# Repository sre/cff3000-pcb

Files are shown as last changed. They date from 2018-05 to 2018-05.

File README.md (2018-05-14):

CFF3000 GPIO interface
======================

This repository contains information how to interface a Abus CFF3000
remote control with a Raspberry Pi or similar development board using
GPIOs. First of all one needs to disassemble the remote control. Be
careful when removing the rubber part from the PCB to avoid tearing
off the antenna.

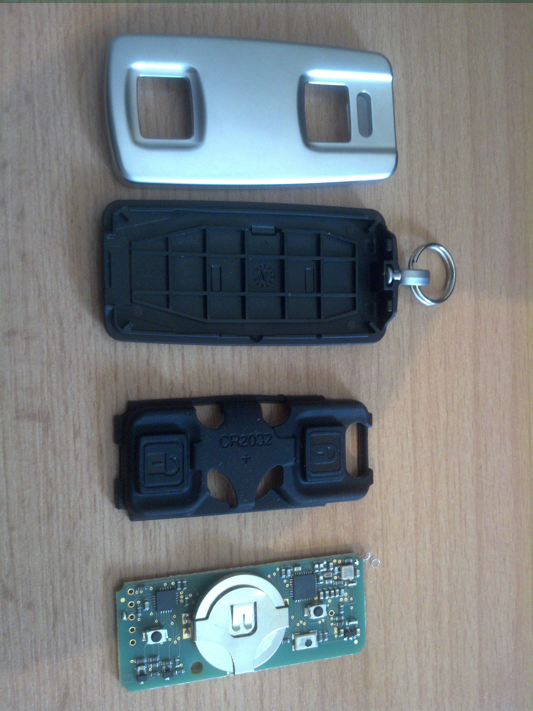
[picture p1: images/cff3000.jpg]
Disassembled CFF3000


Next step: Soldering a couple of wires. I tried to tap the signals
at locations, that are as simple to solder as possible. Unfortunately
tapping the LEDs is a bit tricky. Note, that the CFF3000 design is
"interesting" and does not use a common ground/vcc for the buttons
and LEDs.

Wire locations

To work around the problem with uncommon ground/vcc, I made a small
single layer PCB. Some explanations for the schematics: The CFF3000
is connected on the right side of the schematics. Each buttons is
connected to a opto-coupler, the other side of the opto-coupler is
connected to the computer's GPIO through a resistor as current limiter.
The LEDs are also connected to a opto-coupler, but the signal is
additionally inverted and cleaned by a schmitt-trigger. This was
necessary for proper reading of the green LED. Also the green LED
channel has a 100Hz RC lowpass filter (47nF, 33K), since it is driven
with a 1KHz PWM signal by the CFF3000 and we want a logical 1 or 0
instead.

Schematic
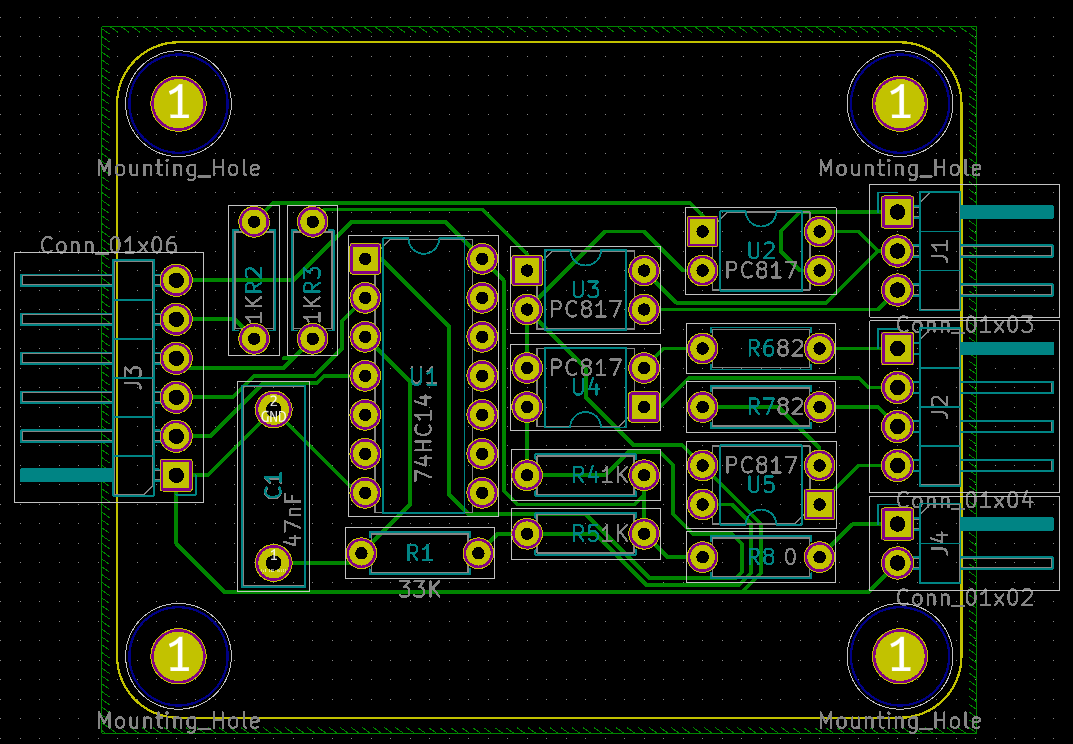
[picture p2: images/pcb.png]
PCB


License
=======

© 2018 Sebastian Reichel

ISC License

Permission to use, copy, modify, and/or distribute this software for
any purpose with or without fee is hereby granted, provided that the
above copyright notice and this permission notice appear in all copies.

THE SOFTWARE IS PROVIDED "AS IS" AND THE AUTHOR DISCLAIMS ALL WARRANTIES
WITH REGARD TO THIS SOFTWARE INCLUDING ALL IMPLIED WARRANTIES OF
MERCHANTABILITY AND FITNESS. IN NO EVENT SHALL THE AUTHOR BE LIABLE FOR
ANY SPECIAL, DIRECT, INDIRECT, OR CONSEQUENTIAL DAMAGES OR ANY DAMAGES
WHATSOEVER RESULTING FROM LOSS OF USE, DATA OR PROFITS, WHETHER IN AN
ACTION OF CONTRACT, NEGLIGENCE OR OTHER TORTIOUS ACTION, ARISING OUT OF
OR IN CONNECTION WITH THE USE OR PERFORMANCE OF THIS SOFTWARE.

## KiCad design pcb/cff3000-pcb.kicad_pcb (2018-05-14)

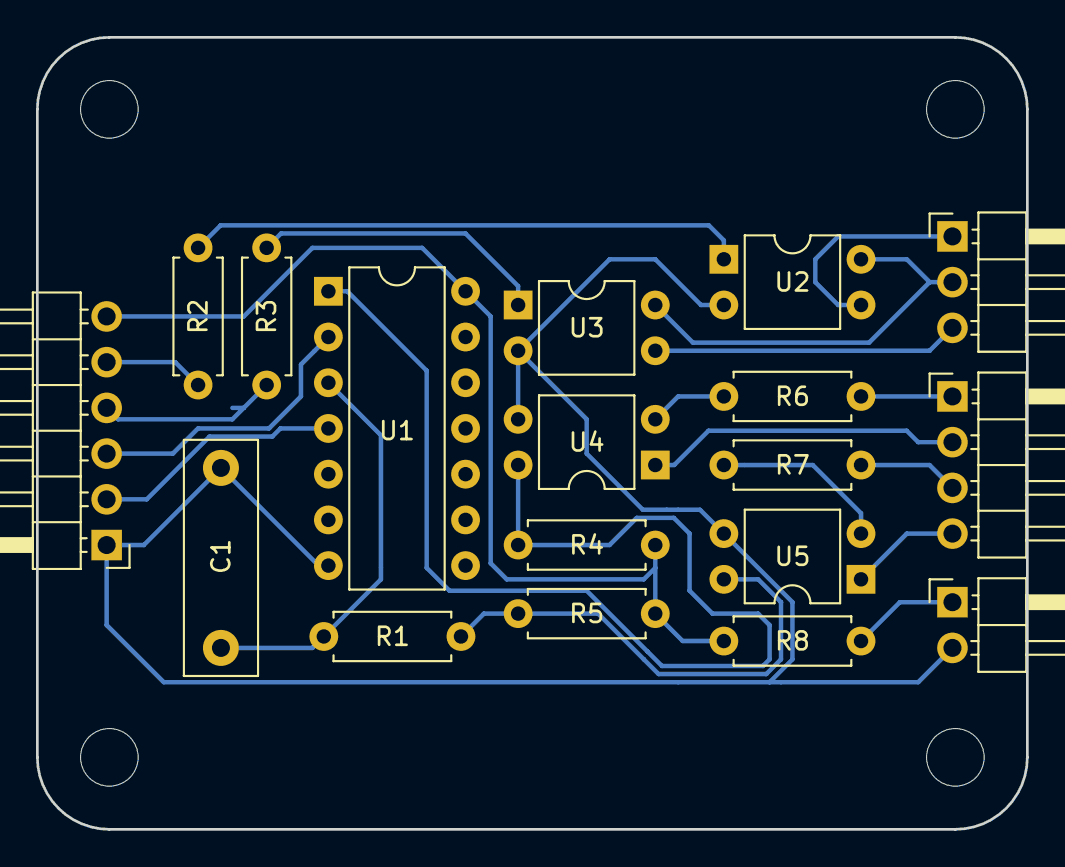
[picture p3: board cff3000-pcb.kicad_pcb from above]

Board: 2 copper layers, 55.0 x 44.0 mm, 22 parts (0 on the bottom side), 21 nets.

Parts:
C1: 47nF; C_Rect_L13.0mm_W4.0mm_P10.00mm_FKS3_FKP3_MKS4
J1: Conn_01x03; PinHeader_1x03_P2.54mm_Horizontal
J2: Conn_01x04; PinHeader_1x04_P2.54mm_Horizontal
J3: Conn_01x06; PinHeader_1x06_P2.54mm_Horizontal
J4: Conn_01x02; PinHeader_1x02_P2.54mm_Horizontal
MK1, MK2, MK3, MK4: Mounting_Hole; MountingHole_3.2mm_M3
R1: 33K; R_Axial_DIN0207_L6.3mm_D2.5mm_P7.62mm_Horizontal
R2, R3, R4, R5: 1K; R_Axial_DIN0207_L6.3mm_D2.5mm_P7.62mm_Horizontal
R6, R7: 82; R_Axial_DIN0207_L6.3mm_D2.5mm_P7.62mm_Horizontal
R8: 0; R_Axial_DIN0207_L6.3mm_D2.5mm_P7.62mm_Horizontal
U1: 74HC14; DIP-14_W7.62mm
U2, U3, U4, U5: PC817; DIP-4_W7.62mm

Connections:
/BUTTONS+: J1.2, U2.4, U3.4
/GPIO_GREEN: J3.2, U1.4
/GPIO_LOCK: J3.4, R3.2
/GPIO_RED: J3.3, U1.2
/GPIO_UNLOCK: J3.5, R2.2
/GREEN+: J2.4, U5.1
/GREEN-: J2.3, R7.1
/LOCK: J1.3, U3.3
/RED+: J2.2, U4.1
/RED-: J2.1, R6.1
/UNLOCK: J1.1, U2.3
GND: C1.2, J3.1, J4.2, U1.7, U2.2, U3.2, U4.3, U5.3
unnamed: C1.1, R1.1, U1.3
unnamed: J4.1, R8.1
unnamed: R1.2, R5.1, U5.4
unnamed: R2.1, U2.1
unnamed: R3.1, U3.1
unnamed: R4.1, U1.1, U4.4
unnamed: R6.2, U4.2
unnamed: R7.2, U5.2
VCC: J3.6, R4.2, R5.2, R8.2, U1.14

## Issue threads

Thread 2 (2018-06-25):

kicad file with ports to connect the pcb directli to raspberry pi 3B+

dennis82m, 2018-06-25:
Just as an idea it may be possible to design the pcb in a way it would be able to be directly applied to the gpio pins of the rapsberry pi 3b plus? and maybee there is a way to somehow „include“ the remote onto the pcb and remove the battery from it?

sre, 2018-06-25:
You can already remove the battery when you connect the remote control's Vcc to the PCB. I use the SoC's 3V3 as power supply for the remote control. Actually you should only connect either the remote control's Vcc line OR insert the battery, but not both at the same time.

Of course you can modify the form factor of the PCB, so that it becomes a RPi hat and/or add some space for the remote control pcb. I provided the PCB as documentation for the electrical wiring.

I suppose the clean solution would be to analyze the data sent between the [PIC16LF1829](http://ww1.microchip.com/downloads/en/DeviceDoc/41440B.pdf) micocontroller (sidenote: the 5 pin connector on the PCB is connected its ICSP interface) and the [MRF89XA](http://ww1.microchip.com/downloads/en/DeviceDoc/70000622D.pdf) RF chip on the remote control and design a new PCB with onboard RF chip directly wired to the single board computer.

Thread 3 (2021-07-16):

Green - and Green + are not distinguishable

JanZimmer, 2021-07-16:
Unfortunately, the + and - terminal of the green LED are both labeled as - in the photo of the CFF3000.

sre, 2021-07-16:
That's probably a problem with your SVG renderer. It looks ok for me in Firefox and Chromium. The cathode (-) of the green LED is on the side of the battery and thus the anode (+) of the green LED is close to the PCB edge.

Since I created this Github project, I spent some time analyzing the remote control's circuit. I still need to update this repository for this, but the summary:

* The micro-controller controls the cathode of each LED (i.e. it will go HIGH when the LED is supposed to be off)
* The green LED is driven by a charge pump circuit resulting in PWM signal on its anode
* The battery + is not Vcc, but BAT+. There is a transistor connecting it to Vcc when a button is pressed and micro-controller will keep it enabled until it has done its job.
* Vcc is the middle one of the big vias (i.e. where GND is marked in the photo) and can be used as RED+ and GREEN+, which is easier to solder and avoids having to fiddle with the charge pump.

I plan to update this project with more details soon.

JanZimmer, 2021-07-16:
Thanks for the fast update. As I'm a beginner to electronics:
What implications do these updates have?
- I got that I can solder VCC (middle big via or "hole") to RED+ and GREEN+.
- Does this also hold for VCC or do I still have to grab it from the battery?
- What about BUTTON+? Is this also VCC? (Are Buttons active high or low?)
- Is there a more convenient spot to grab GREEN-?

Btw, what are the other three big vias? SWD/JTAG? UART? Have you tried looking into them?

As I just finished to solder the whole thing: will there be an significant update to it? (Hopefully not :D)

Also, I could provide my BOM as there are no exact part numbers and I had to guess them (honestly, it also could be the case that I'm just stupid :D).

sre, 2021-07-16:
> Btw, what are the other three big vias? SWD/JTAG? UART? Have you tried looking into them?

The big vias are for programming the PIC16LF:

 * 1 = GND
 * 2 = VPP (which is the same as the LOCK button signal)
 * 3 = VCC
 * 4 = ICSP_DATA
 * 5 = ICSP_CLK

> As I just finished to solder the whole thing: will there be an significant update to it? (Hopefully not :D)

On my original board R1 and C1 were meant to filter the PWM noise from the charge pump. With the noise gone (by using Vcc instead of GREEN+) those should be removed. I also replaced the 74HC14 and the PC817 with a two comparators, but the original design should also work.

> Does this also hold for VCC or do I still have to grab it from the battery?

I have not yet tested this. Using VCC instead of BAT+ to supply the board means, that the micro-controller will keep being powered. This will draw slightly more power, but we are talking about mW (so a problem for a coin cell, but neglectable when you power a Raspberry-Pi or sth. similar in parallel). Using it should not break anything, but IDK if the software running on the PIC16 can handle being powered all the time. You will have to test it :)

> What about BUTTON+? Is this also VCC? (Are Buttons active high or low?)

LOCK and UNLOCK are pulled to GND with 3.3K on the remote control. Pressing the button will connect the pins to BUTTONS+ respectively, so the buttons are active-high. BUTTONS+ is connected to BAT+ with a 33K resistor, since the buttons also enable the transistor, which supplies Vcc from BAT+. If you use Vcc instead of BAT+ to supply the circuit, you should also get away to use VCC for BAT+.

> Is there a more convenient spot to grab GREEN-?

There is a more convenient spot to grab the LOCK button, which is the via between GND and VCC. The board reuses VPP for the lock button signal. For GREEN- you might find the small VIA between the PIC16 and the unlock button more convenient (the one, which is closest to the unlock button).

> Also, I could provide my BOM as there are no exact part numbers

I just used parts laying around in my hackerspace. The exact component should not really matter as long as the values roughly match. Value-wise the only interesting part was the filter for the charge pump PWM and that is gone due to using Vcc.

JanZimmer, 2021-07-16:
> On my original board R1 and C1 were meant to filter the PWM noise from the charge pump. With the noise gone (by using Vcc instead of GREEN+) those should be removed.

This means I just remove them or I have to bridge (one or both of) them?

> I have not yet tested this. Using VCC instead of BAT+ to supply the board means, that the micro-controller will keep being powered. This will draw slightly more power, but we are talking about mW (so a problem for a coin cell, but neglectable when you power a Raspberry-Pi or sth. similar in parallel). Using it should not break anything, but IDK if the software running on the PIC16 can handle being powered all the time. You will have to test it :)

This could be handled by either driving the whole thing via a GPIO and do the power cycle in software. Not the best idea, though, as GPIOs on the Pi allow for max. current of 16mA. I'd assume, that the board especially while sending, draws more current. Maybe I could use a transistor to circumvent this.

> [...]  If you use Vcc instead of BAT+ to supply the circuit, you should also get away to use VCC for BAT+.

This results in two options to power the whole thing, right?

Option 1:
VCC_J4 -> BAT+
Then, Button+ must be grabbed as intended in the original sketch. (**Question: is this correct or can I connect  Button+ to VCC_CFF or VCC_J4 instead?**)
Green+ and Red+ on the board can be connected to VCC_CFF (middle via) instead.

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

Option 2:

VCC_J4 -> VCC_CFF
Then, Button+, Green+, Red+ on the board can also be connected to VCC_J4.
Might not work, if software needs powercycle, see above.

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

sre, 2021-07-16:
> > On my original board R1 and C1 were meant to filter the PWM noise from the charge pump. With the noise gone (by using Vcc instead of GREEN+) those should be removed.
>
> This means I just remove them or I have to bridge (one or both of) them?

Drop C1, bridge R1 (i.e. make it look the same as the route for the red LED)

> > I have not yet tested this. Using VCC instead of BAT+ to supply the board means, that the micro-controller will keep being powered. This will draw slightly more power, but we are talking about mW (so a problem for a coin cell, but neglectable when you power a Raspberry-Pi or sth. similar in parallel). Using it should not break anything, but IDK if the software running on the PIC16 can handle being powered all the time. You will have to test it :)
>
> This could be handled by either driving the whole thing via a GPIO and do the power cycle in software. Not the best idea, though, as GPIOs on the Pi allow for max. current of 16mA. I'd assume, that the board especially while sending, draws more current. Maybe I could use a transistor to circumvent this.

16 mA is not enough. Driving it through a transistor should work. It might also be ok to keep it enabled all the time (as I said I have not tested this).

> This results in two options to power the whole thing, right?

Yes, looks sensible. As I said you can get LOCK from the hole between VCC and GND.

HacksBugsAndRockAndRoll, 2021-07-26:
As I am about to start tinkering with this soon. Is there a chance on getting an updated schematic with these simplifications?

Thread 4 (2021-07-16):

Is VCC and GND of GPIO domain the same as CFF3000 domain?

JanZimmer, 2021-07-16:
Is VCC and GND on J3 (GPIO domain) the same as on J4 (CFF domain)?
I would assume no, right (should come from, e.g., raspi).
Then, what voltage level is it designed for?

Also, is there a possibility to drive the whole CFF via the Pi's VCC (possibly with a step-down converter)?

sre, 2021-07-16:
The purpose of J4 is supplying the CFF with power, so yes VCC on J3 and J4 are the same. With R8 soldered in you should remove the battery from the CFF. Then J3 should be supplied with 3.3V on the Vcc pin. Don't apply 5V, since that can fry the MRF89XA on the CFF (it is only specified for up to 3.6V).
